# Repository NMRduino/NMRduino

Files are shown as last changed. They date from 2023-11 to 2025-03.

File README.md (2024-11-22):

# A modular, open-source platform for sub-MHz NMR

### Introduction
Many students, researchers and hobbyists will be familiar with the [Arduino](https://arduino.cc) open-source-electronics ecosystem, which provides an extraordinarily simple way to interface sensors (or other input devices) and actuators (output) with logic programs, e.g. C code, to create a wide variety of standalone control devices termed embedded systems.  A [Nuclear Magnetic Resonance](https://en.wikipedia.org/wiki/Nuclear_magnetic_resonance) (**NMR**) spectrometer can be regarded as one specific type of embedded system: the output is a magnetic field produced by a coil, the input is a magnetic field (detected and recorded by a digitizer), and a pulse programmer keeps timing and data in order.

The **NMRduino** is a magnetic resonance spectrometer based on (but we must stress, not endorsed or supported by) Arduino that we have developed over recent years to study hyperpolarized NMR systems, NMR relaxation, high-resolution spectroscopy, and coherent control at low magnetic fields, as well as teach basic principles of magnetic resonance to student beginners

Main features are:

-  Compact, plug-and-play hardware.  A credit-card-sized circuit board contains all electronic components and connects to any laptop, desktop or Raspberry Pi computer via USB.  Includes pulse programmer and analog sampling up to 100 kHz.

-  Transparent, intuitive control interface.  User-specific pulse sequences (1 μs time resolution) can be written to control both DC and AC magnetic fields up to several hundred kHz.  Open access to low-level programming interface for advanced users.

-  Flexibility.  Can be connected to conventional rf-inductive pickup coils, or alternative sensors such as atomic magnetometers.

### Software

To get running, you'll need a copy of NMRduino's firmware: [Latest version here](https://github.com/NMRduino/NMRduino/blob/main/Software/MCU/index.md)

plus the user interface. Select the version for your operating system: [Raspberry Pi](https://github.com/NMRduino/), [Windows xx](https://github.com/NMRduino/)

### External resources
[NMRduino at Open Source Imaging](https://www.opensourceimaging.org/project/nmrduino/), a directory of FOSS/OSHW magnetic resonance projects </br>
[NMRduino in the Journal of Magnetic Resonance](https://doi.org/10.1016/j.jmr.2024.107665).  A FREE TO READ article written by the creators of NMRduino, published May 2024

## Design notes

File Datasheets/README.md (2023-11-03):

# Datasheets index

In this folder, you can find datasheets for each of the modular components used in NMRduino.  These are valid for the latest version of NMRduino. 

- Teensy 4.1 microcontroller
    - _Teensy4.1web.pdf_  - Web capture of the Teensy 4.1 specification from PJRC.com
    - _Teensy4.1 Pins.pdf_  - Default pin and port mapping for Teensy 4.1
    - _IMXRT1060RM_rev3.pdf_ - The IMXRT1060 programming manual.  This is a large file (> 25 MB) and can be downloaded from PJRC instead: [https://www.pjrc.com/teensy/IMXRT1060RM_rev3.pdf](https://www.pjrc.com/teensy/IMXRT1060RM_rev3.pdf)
    -  _Teensy4_1_card11a_rev4_web_front.pdf_ and _Teensy4_1_card11a_rev4_web_front.pdf_ - Quick reference card for Teensy 4.1

- DAC module
   - _MCP482X.pdf_ - Datasheet for Microchip's MCP4822 dual-channel 12-bit digital-to-analog converter
   - _L272.pdf_ - Datasheet for Analog Devices' L272D dual-channel operational amplifier
   - _drv8838.pdf_ - Datasheet for Texas Instruments' single-channel H-bridge IC DRV8838
   - _drv8838-dual-motor-driver-carrier-dimensions.pdf_ - Specific data for Pololu DRV8838 carrier board
   - _drv8838-dual-motor-driver-carrier-schematic.pdf_ - Circuit layout for Pololu DRV8838 carrier board

- Digital output channels
   - _drv8835.pdf_ - Datasheet for Texas Instruments' dual-channel H-bridge IC DRV8835
   - _drv8835-dual-motor-driver-carrier-dimensions.pdf_ - Specific data for Pololu DRV8835 carrier board

- ADC module
   - _LTC185X.pdf_ - Datasheet for Analog Devices' 8-channel, 16-bit analog-to-digital converter IC LTC1859 
   - _MAX1300-MAX1301.pdf_ - Datasheet for MAXIM Integrated's 16-bit analog-to-digital converter MAX1301

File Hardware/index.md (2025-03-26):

# PCB Gerber files for NMRduino

## Description 
Gerber files for PCB manufacture.  The files uses standard naming conventions for a two-layer PCB.  Download the [Gerber ZIP file here](https://github.com/NMRduino/NMRduino/blob/main/Hardware/NMRduino-GERBER-Rev0923.zip).

A schematic will be added in due course

## License
NMRduino hardware designs are released under a Creative Commons Attribution ShareAlike (CC-BY-SA, [read the license here](https://creativecommons.org/licenses/by-sa/4.0/deed)).  By using NMRduino, you agree to the terms of this license.

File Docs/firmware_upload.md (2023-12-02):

# Uploading the Firmware to NMRduino

This guide will walk you through the process of uploading a firmware to
NMRduino.

## Prerequisites

Before you start, ensure you have the following:

-    An NMRduino, equipped with a Teensy 4.1 microcontroller (see
[https://www.pjrc.com/store/teensy41.html](https://www.pjrc.com/store/teensy41.html))
-    A computer running Windows, macOS, or Linux
-    A USB to micro-USB cable with power and data lines
-    An installed version of the Arduino Integrated Development
Environment (IDE, see
[https://www.arduino.cc/en/software](https://www.arduino.cc/en/software))

## Install Teensyduino

Teensy microcontrollers require additional software to be installed,
known as "Teensyduino", before being programmed with the Arduino IDE. To
install Teensyduino, follow these steps:

1.   Download the latest Teensyduino installer from the PJRC website.
[https://www.pjrc.com/teensy/td_download.html](https://www.pjrc.com/teensy/td_download.html)

1.   Run the installer and follow the on-screen instructions to complete
the installation.

1.   Restart the Arduino IDE.

## Configure Arduino IDE

After installing Teensyduino, one needs to select the Teensy board, CPU
speed, USB port, and other parameters from a list within the Arduino IDE.

Connect the NMRduino to your computer using a compatible USB cable,
usually USB to micro-USB. Then,

1.    Within the Arduino IDE, open the "Tools" menu and under the
"Boards" submenu, select the Teensy board model: "Board -> Teensy ->
Teensy 4.1".

1.    Also choose "USB Type -> Serial", "CPU Speed -> 600 MHz",
"Optimize -> Faster".

1.    Set the USB port to where your Teensy is connected, again from the
"Tools" menu and by selecting "Port -> ... (Teensy 4.1)".  If the board
is not listed, check that the Teensy is receiving power over USB.
Alternatively, check the computer's device manager for connected ports.

## Download the NMRduino/Teensy firmware from GitHub

The most up-to-date NMRduino firmware will always be located on this GitHub
repository.

1.    Visit [../Software/MCU/latest](../Software/MCU/latest) to download the latest version of NMRduino.

1.    Click on the green "Code" button, and then click "Download ZIP" to
download the firmware as a ZIP file.

1.    Extract the contents of the ZIP file to a location on your computer.

## Upload the Program to Teensy

To upload the firmware from the downloaded repository to your Teensy
board, follow these steps:

1.    Open the Arduino IDE.

1.    Go to "File" > "Open" and navigate to the folder where you
extracted the GitHub repository.

1.    Select the main program file (".ino" extension).

1.    Click the right-arrow icon in the top-left of the IDE window (or
go to "Sketch" > "Upload") to upload the code to the Teensy board.

1.    The Arduino IDE will compile your code and then upload it to the
Teensy. You will see the upload progress in the status bar at the bottom
of the IDE.

1.    Once the upload is successful, you should see a "Done uploading"
message in the status bar.  The Arduino IDE can now be closed.

## Troubleshooting

If you encounter any issues during the upload process, consider the
following troubleshooting steps:

-    Check your connections and ensure the computer and Teensy are
properly connected via USB.
-    Verify that the correct Teensy board and port has been selected in
the Arduino IDE.
-    Restart the Arduino IDE if necessary.
-    Consult the [Teensy
documentation](https://www.pjrc.com/teensy/tutorial.html) and [PJRC
forum](https://forum.pjrc.com/) for more specific troubleshooting.

Congratulations! You have successfully uploaded the firmware to your
NMRduino.

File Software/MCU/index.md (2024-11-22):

# NMRduino firmware release

## Description 
Microcontroller code for NMRduino.  Compatible with [Teensy 4.1](https://www.pjrc.com/store/teensy41.html)

## Latest version
**Last update:** 22/11/2024. [Code available here](https://github.com/NMRduino/NMRduino/tree/main/Software/MCU/latest)  

**Compatibility:** UI version 3.43+.

**Compilation:** Compile using a Teensyduino-extended Arduino IDE using options *"Teensy 4.1", "600 MHz", "Faster"*.

Please check back for updates.  When you update firmware, check for UI version compatibility.  

In future, compatibility checking will be an automatic feature of the UI.  For now though, you need to do it.

## Hex file
If you prefer simplicity, and don't want to edit the code, a compiled HEX file is also available:  [Latest version](https://github.com/NMRduino/NMRduino/blob/main/Software/MCU/latest/NMRduino_v1.01-GPL3-release.ino.hex).

The HEX file can be uploaded to the MCU using [Teensy Loader](https://www.pjrc.com/teensy/loader.html).

## License
You use this software at your own risk and liability.  You also agree to obey the license agreement(s) outlined below.  

All files contained in the NMRduino/Software/MCU/ directory are licensed under the [GNU General Public License 3.0](https://www.gnu.org/licenses/gpl-3.0.en.html#license-text).  The applicable copy of this license is contained [here](https://github.com/NMRduino/NMRduino/blob/main/Software/MCU/License/gpl-3.0.txt).

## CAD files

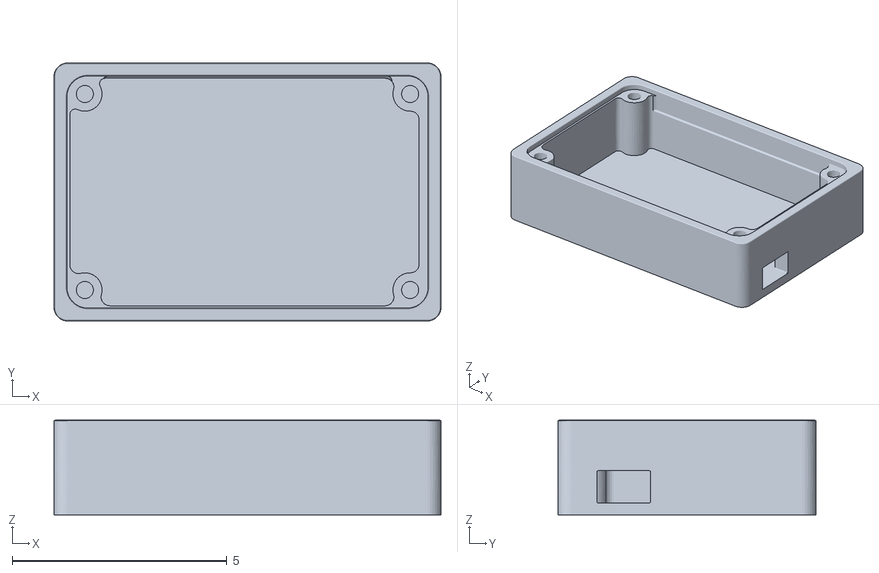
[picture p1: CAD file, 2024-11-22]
Software/Print3D/NMRduino-case-v1-112024.stl
9.00 x 6.00 x 2.20

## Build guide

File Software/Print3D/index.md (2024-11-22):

# 3D-printable case for NMRduino

## Description 
Place your NMRduino inside this smart protective case.  This helps the module to sit neatly on your table, as well as avoid unintentional electrical shorts to connections on the underside of the board.

## Latest file
[NMRduino/Software/Print3D/NMRduino-case-v1-241120.stl](https://github.com/NMRduino/NMRduino/blob/main/Software/Print3D/NMRduino-case-v1-242011.stl)  

## Best printing material
ABS or PLA filament. Afterwards, one can place threaded inserts; we recommend Ruthex's product RX-M2.5x5.7 ([Amazon link](https://www.amazon.es/ruthex-inserto-roscado-M2-5-piezas/dp/B088QJDPKK), working 11/2024)

## License
Use of all files contained in the NMRduino/Software/Print3D/ directory is licensed under the [Creative Commons Attribution-Sharealike license version 4.0](https://creativecommons.org/licenses/by-sa/4.0/deed.en)

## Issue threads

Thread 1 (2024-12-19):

Schematic amd Layout of the entire board

anuraj-rp, 2024-12-19:
Hi,

Is it possible to upload the schematic and layout gerber files of the entire board.

I didn't find it in the repo.

NMRduino, 2025-03-26:
Hi, we have added Gerber files. A schematic will follow shortly. See the "Hardware" folder.

anuraj-rp, 2025-06-02:
Any update on the schematic?

> Hi, we have added Gerber files. A schematic will follow shortly. See the "Hardware" folder.

Closed 2025-03-26.

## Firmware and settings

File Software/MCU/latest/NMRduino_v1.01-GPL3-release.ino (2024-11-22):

/*  NMRduino open core version 1.01
*   Compatible with Teensy 4.1 and NMRduino UI version(s) 3.34.3
*   Copyright (C) 2024, by Michael Tayler and Sven Bodenstedt
*
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
* You should have received a copy of the GNU General Public License
* along with this program.  If not, see <http://www.gnu.org/licenses/>.
*/

enum State {State_Idle, State_Init, State_Sequence, State_Acquire, State_Transfer, State_GPIO_change, State_acq_get, State_acq_rtn, State_dac_rtn, State_acq_point_init}; //, State_Flush};
volatile State state = State_Idle;
#include "serial.h"

void setup(){ 
  state=State_Idle;
  Serial_init();
  }
  
void loop(){
switch (state)
  {
  case State_Idle:
    while(readSerialData()){}
    state = State_Init;
  break;
      
  case State_Init: 
    seq_run();
  break;

  case State_Transfer:
    transfer_data(n_data_points);
    delay(1);
    state=State_Idle;
  break;

  default: 
  break;
  }
}

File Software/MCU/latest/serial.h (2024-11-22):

/*  NMRduino open core version 1.01
*   Compatible with Teensy 4.1 and NMRduino UI version(s) 3.34.3
*   Copyright (C) 2024, by Michael Tayler and Sven Bodenstedt
*
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
* You should have received a copy of the GNU General Public License
* along with this program.  If not, see <http://www.gnu.org/licenses/>.
*/

#ifndef serial_h
#define serial_h

#include <SPI.h>
#include "sequences.h"

byte serialData[64];
const byte bits_per_event = 8;  
const byte overhead_bits = 8;

void Serial_init() {
  Serial.begin(115200);  //start Serial  
  SPI_init();
  delay(10);
  pinMode(23,OUTPUT);   digitalWriteFast(23,LOW); // D0
  pinMode(22,OUTPUT);   digitalWriteFast(22,LOW);
  pinMode(21,OUTPUT);   digitalWriteFast(21,LOW); // D1
  pinMode(20,OUTPUT);   digitalWriteFast(20,LOW); 
  pinMode(19,OUTPUT);   digitalWriteFast(19,LOW); // D2
  pinMode(18,OUTPUT);   digitalWriteFast(18,LOW);
  pinMode(15,OUTPUT);   digitalWriteFast(15,LOW); // A0
  pinMode(14,OUTPUT);   digitalWriteFast(14,LOW); 
  pinMode(41,OUTPUT);   digitalWriteFast(41,LOW); // A1
  pinMode(40,OUTPUT);   digitalWriteFast(40,LOW);  
  dac_init(); 
}

void print_error(byte err){
  Serial.write(err);
  Serial.send_now();
}

void read_all(){ while (Serial.available() > 0){Serial.read();}}
  
int readSerialData(){
  while (Serial.available() == 0){ }

  if (Serial.readBytes((char*)serialData, 1) != 1){print_error(1); return 1;}   

  else if (serialData[0] == 0x00){print_error(0); return 1;} 

  if (serialData[0] != 0xA5){read_all(); print_error(1); return 1;} 

  if (Serial.readBytes((char*)serialData+1, 2) != 2){read_all(); print_error(1); return 1;} 

  size_t serialDataLength;

  if (serialData[1] < 0x80){serialDataLength = 18;}  else {serialDataLength = serialData[2];}
  if (serialDataLength > 64){print_error(1); return 1;}
  
  if (Serial.readBytes((char*)(serialData+3), serialDataLength-3) != (serialDataLength-3)){read_all(); print_error(1); return 1;}
  else if(serialData[serialDataLength-1] != 0x5A){read_all(); print_error(1); return 1;} 

  if (serialData[1] >= 0x80){print_error(0);}
  if (serialData[1] <= 0x80){
    n_data_points   = serialData[2]*512; // number of data points times 512
    seq_sampleperiod        = (serialData[10] << 8) + serialData[11];
    seq_acquisition_mode    = serialData[1]; 
    return 0;
  }  
  if(serialData[1] == 0x81){
    n_events = (serialData[3] << 8) + serialData[4]; 
    unsigned int currentevent = (serialData[5] << 8) + serialData[6]; 
    unsigned int n_currentevent = (serialDataLength - overhead_bits) / bits_per_event; // number of events in current serial command
    unsigned int dataIndex, pulseIndex;

    if ((serialDataLength - overhead_bits) % bits_per_event){return 1;} 
    else if (n_events > MAX_NUMBER_EVENTS - 1) {return 1;} 
    else if((currentevent + n_currentevent) > n_events){return 1;}  
    for (unsigned int i=0; i < n_currentevent; i++){
      pulseIndex = currentevent + i;
      dataIndex = (overhead_bits - 1) + i*bits_per_event;
      
      gpio_time[pulseIndex] = (  (serialData[dataIndex + 0] << 24) +
                                 (serialData[dataIndex + 1] << 16) +
                                 (serialData[dataIndex + 2] <<  8) +
                                 (serialData[dataIndex + 3]      )  );
      gpio_set[pulseIndex] =  (  (serialData[dataIndex + 4] << 24) +
                                 (serialData[dataIndex + 5] << 16) +
                                 (serialData[dataIndex + 6] <<  8) +
                                 (serialData[dataIndex + 7]      )  );  
      gpio_clr[pulseIndex] =  (~((serialData[dataIndex + 4] << 24) +
                                 (serialData[dataIndex + 5] << 16) +
                                 (serialData[dataIndex + 6] <<  8)) );                                      
    }

    return 1;
  }

  return 1;
}

#endif // serial_h

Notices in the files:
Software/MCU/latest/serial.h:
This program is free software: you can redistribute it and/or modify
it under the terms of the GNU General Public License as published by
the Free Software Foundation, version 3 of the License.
